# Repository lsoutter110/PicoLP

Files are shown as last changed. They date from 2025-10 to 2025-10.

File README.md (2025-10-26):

# PicoLP

STM32 development board, designed within the Raspberry Pi Pico footprint.

## Getting Started

A pinout for the board is provided in `documentation`, and example projects are provided in `firmware`. To build an example using CMake/VSCode:
- Clone the repo
- Import the project with the STM32Cube extension
- Configure the build options when prompted (Debug/Release)
- Configure as default and run the Build+Flash task with the STLink attached to the board

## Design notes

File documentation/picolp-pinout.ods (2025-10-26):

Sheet: template
NRST |  |  |  |  | VIN
3V3 |  |  |  |  | 3V3
GND |  |  |  |  | GND
B3 |  |  |  |  | A15
B4 |  |  |  |  | A10
B5 |  |  |  |  | A9
B6 |  |  |  |  | A8
GND |  |  |  |  | GND
B7 |  |  |  |  | B15
B8 |  |  |  |  | B14
B9 |  |  |  |  | B13
A0 |  |  |  |  | B12
GND |  |  |  |  | GND
A1 |  |  |  |  | B11
A2 |  |  |  |  | B10
A3 |  |  |  |  | B2
A4 |  |  |  |  | B1
GND |  |  |  |  | GND
A5 |  |  |  |  | B0
A6 |  |  |  |  | A7
 | PVIN | SWDIO | SWCLK | GND

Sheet: L051
TIM | I2C | SPI | UART | ADC | PIN |  |  |  |  | PIN | ADC | UART | SPI | I2C | TIM
 |  |  |  |  | NRST |  |  |  |  | VIN
 |  |  |  |  | 3V3 |  |  |  |  | 3V3
 |  |  |  |  | GND |  |  |  |  | GND
2CH2 |  | 1SCK |  |  | B3 |  |  |  |  | A15 |  | 2RX | 1NSS |  | 2CH1
22CH1 |  | 1MISO |  |  | B4 |  |  |  |  | A10 |  | 1RX
22CH2 |  | 1MOSI |  |  | B5 |  |  |  |  | A9 |  | 1TX
 | 1SCL |  | 1TX |  | B6 |  |  |  |  | A8
 |  |  |  |  | GND |  |  |  |  | GND
L1IN2 | 1SDA |  | 1RX |  | B7 |  |  |  |  | B15 |  |  | 2MOSI
 | 1SCL |  |  |  | B8 |  |  |  |  | B14 |  |  | 2MISO | 2SDA | 21CH2
 | 1SDA | 2NSS |  |  | B9 |  |  |  |  | B13 |  |  | 2SCK | 2SCL | 21CH1
2CH1 |  |  |  | IN0 | A0 |  |  |  |  | B12 |  |  | 2NSS
 |  |  |  |  | GND |  |  |  |  | GND
2CH2 |  |  |  | IN1 | A1 |  |  |  |  | B11 |  | L1RX |  | 2SDA | 2CH4
2CH3 |  |  | 2TX | IN2 | A2 |  |  |  |  | B10 |  | L1TX | 2SCK | 2SCL | 2CH3
2CH4 |  |  | 2RX | IN3 | A3 |  |  |  |  | B2 |  |  |  |  | L1OUT
 |  | 1NSS |  | IN4 | A4 |  |  |  |  | B1 | IN9
 |  |  |  |  | GND |  |  |  |  | GND
2CH1 |  | 1SCK |  | IN5 | A5 |  |  |  |  | B0 | IN8
22CH1 |  | 1MISO |  | IN6 | A6 |  |  |  |  | A7 | IN7 |  | 1MOSI |  | 22CH2
 |  |  |  |  | C13 | PVIN | SWDIO | SWCLK | GND

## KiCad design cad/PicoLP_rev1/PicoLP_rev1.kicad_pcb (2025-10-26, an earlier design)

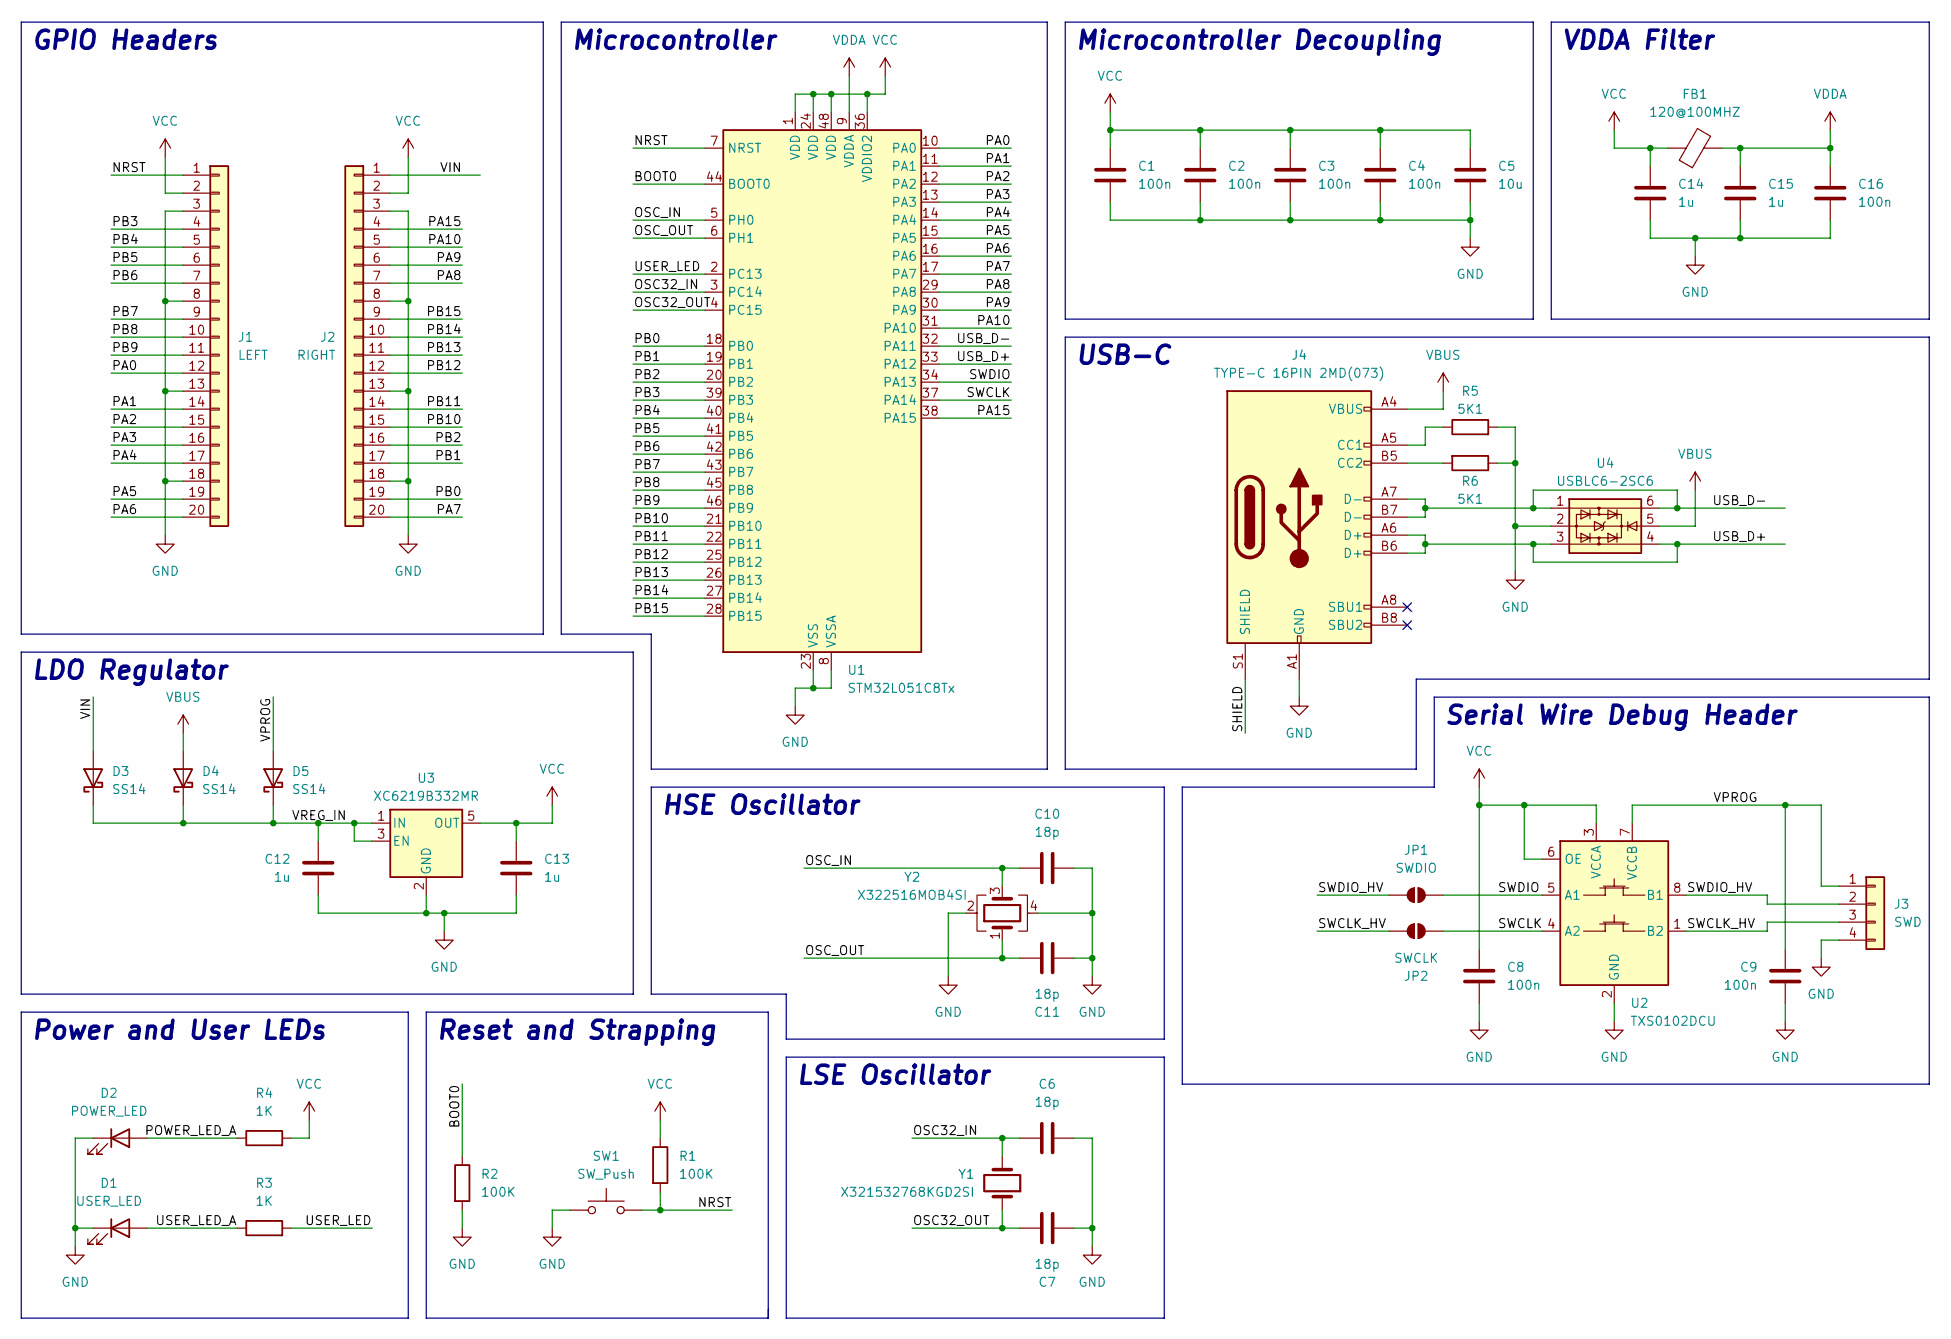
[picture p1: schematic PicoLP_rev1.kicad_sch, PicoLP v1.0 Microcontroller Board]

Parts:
C1, C2, C3, C4, C8, C9, C16: 100n; C_0402_1005Metric
C5: 10u; C_1206_3216Metric
C6, C7, C10, C11: 18p; C_0402_1005Metric
C12, C13, C14, C15: 1u; C_0603_1608Metric
D1: USER_LED; LED_0603_1608Metric
D2: POWER_LED; LED_0603_1608Metric
D3, D4, D5: SS14; D_SMA
FB1: 120@100MHZ; L_0603_1608Metric
J1: LEFT; PinHeader_1x20_P2.54mm_Vertical
J2: RIGHT; PinHeader_1x20_P2.54mm_Vertical
J3: SWD; PinHeader_1x04_P2.54mm_Vertical
J4: TYPE-C 16PIN 2MD(073); USB_C_Receptacle_GCT_USB4105-xx-A_16P_TopMnt_Horizontal
JP1: SWDIO; SolderJumper-2_P1.3mm_Open_TrianglePad1.0x1.5mm
JP2: SWCLK; SolderJumper-2_P1.3mm_Open_TrianglePad1.0x1.5mm
R1, R2: 100K; R_0603_1608Metric
R3, R4: 1K; R_0603_1608Metric
R5, R6: 5K1; R_0603_1608Metric
SW1: SW_Push; TS-1088
U1: STM32L051C8Tx; LQFP-48_7x7mm_P0.5mm
U2: TXS0102DCU; VSSOP-8_2.3x2mm_P0.5mm
U3: XC6219B332MR; SOT-23-5
U4: USBLC6-2SC6; SOT-23-6
Y1: X321532768KGD2SI; Crystal_SMD_3215-2Pin_3.2x1.5mm
Y2: X322516MOB4SI; Crystal_SMD_3225-4Pin_3.2x2.5mm

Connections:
/BOOT0: R2.1, U1.44 (BOOT0)
/NRST: J1.1, R1.2, SW1.2, U1.7 (NRST)
/OSC32_IN: C6.1, U1.3 (PC14), Y1.2
/OSC32_OUT: C7.1, U1.4 (PC15), Y1.1
/OSC_IN: C10.1, U1.5 (PH0), Y2.3
/OSC_OUT: C11.1, U1.6 (PH1), Y2.1
/PA0: J1.12, U1.10 (PA0)
/PA1: J1.14, U1.11 (PA1)
/PA2: J1.15, U1.12 (PA2)
/PA3: J1.16, U1.13 (PA3)
/PA4: J1.17, U1.14 (PA4)
/PA5: J1.19, U1.15 (PA5)
/PA6: J1.20, U1.16 (PA6)
/PA7: J2.20, U1.17 (PA7)
/PA8: J2.7, U1.29 (PA8)
/PA9: J2.6, U1.30 (PA9)
/PA10: J2.5, U1.31 (PA10)
/PA15: J2.4, U1.38 (PA15)
/PB0: J2.19, U1.18 (PB0)
/PB1: J2.17, U1.19 (PB1)
/PB2: J2.16, U1.20 (PB2)
/PB3: J1.4, U1.39 (PB3)
/PB4: J1.5, U1.40 (PB4)
/PB5: J1.6, U1.41 (PB5)
/PB6: J1.7, U1.42 (PB6)
/PB7: J1.9, U1.43 (PB7)
/PB8: J1.10, U1.45 (PB8)
/PB9: J1.11, U1.46 (PB9)
/PB10: J2.15, U1.21 (PB10)
/PB11: J2.14, U1.22 (PB11)
/PB12: J2.12, U1.25 (PB12)
/PB13: J2.11, U1.26 (PB13)
/PB14: J2.10, U1.27 (PB14)
/PB15: J2.9, U1.28 (PB15)
/POWER_LED_A: D2.2 (A), R4.1
/SHIELD: J4.S1 (SHIELD)
/SWCLK: JP2.2 (B), U1.37 (PA14), U2.4 (A2)
/SWCLK_HV: J3.3, JP2.1 (A), U2.1 (B2)
/SWDIO: JP1.2 (B), U1.34 (PA13), U2.5 (A1)
/SWDIO_HV: J3.2, JP1.1 (A), U2.8 (B1)
/USB_D+: J4.A6 (D+), J4.B6 (D+), U1.33 (PA12), U4.3, U4.4
/USB_D-: J4.A7 (D-), J4.B7 (D-), U1.32 (PA11), U4.1, U4.6
/USER_LED: R3.2, U1.2 (PC13)
/USER_LED_A: D1.2 (A), R3.1
/VIN: D3.2 (A), J2.1
/VPROG: C9.1, D5.2 (A), J3.1, U2.7 (VCCB)
/VREG_IN: C12.1, D3.1 (K), D4.1 (K), D5.1 (K), U3.1 (IN), U3.3 (EN)
GND: C1.2, C2.2, C3.2, C4.2, C5.2, C6.2, C7.2, C8.2, C9.2, C10.2, C11.2, C12.2, C13.2, C14.2, C15.2, C16.2, D1.1 (K), D2.1 (K), J1.3, J1.8, J1.13, J1.18, J2.3, J2.8, J2.13, J2.18, J3.4, J4.A1 (GND), J4.A12 (GND), J4.B1 (GND), J4.B12 (GND), R2.2, R5.2, R6.1, SW1.1, U1.8 (VSSA), U1.23 (VSS), U1.35 (VSS), U1.47 (VSS), U2.2 (GND), U3.2 (GND), U4.2, Y2.2, Y2.4
unnamed: J4.A5 (CC1), R5.1
unnamed: J4.B5 (CC2), R6.2
VBUS: D4.2 (A), J4.A4 (VBUS), J4.A9 (VBUS), J4.B4 (VBUS), J4.B9 (VBUS), U4.5
VCC: C1.1, C2.1, C3.1, C4.1, C5.1, C8.1, C13.1, C14.1, FB1.1, J1.2, J2.2, R1.1, R4.2, U1.1 (VDD), U1.24 (VDD), U1.36 (VDDIO2), U1.48 (VDD), U2.3 (VCCA), U2.6 (OE), U3.5 (OUT)
VDDA: C15.1, C16.1, FB1.2, U1.9 (VDDA)

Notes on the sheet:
Reset and Strapping
HSE Oscillator
Serial Wire Debug Header
GPIO Headers
LDO Regulator
LSE Oscillator
USB-C
Power and User LEDs
Microcontroller
VDDA Filter
Microcontroller Decoupling

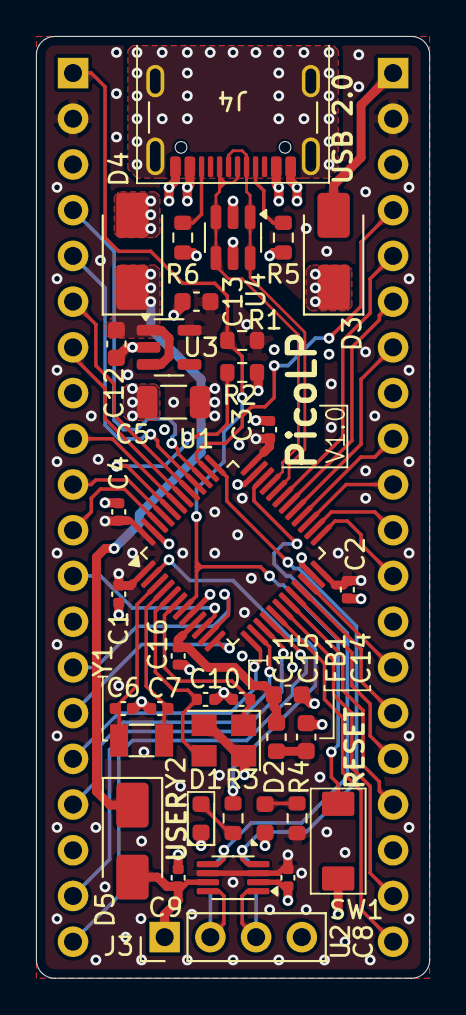
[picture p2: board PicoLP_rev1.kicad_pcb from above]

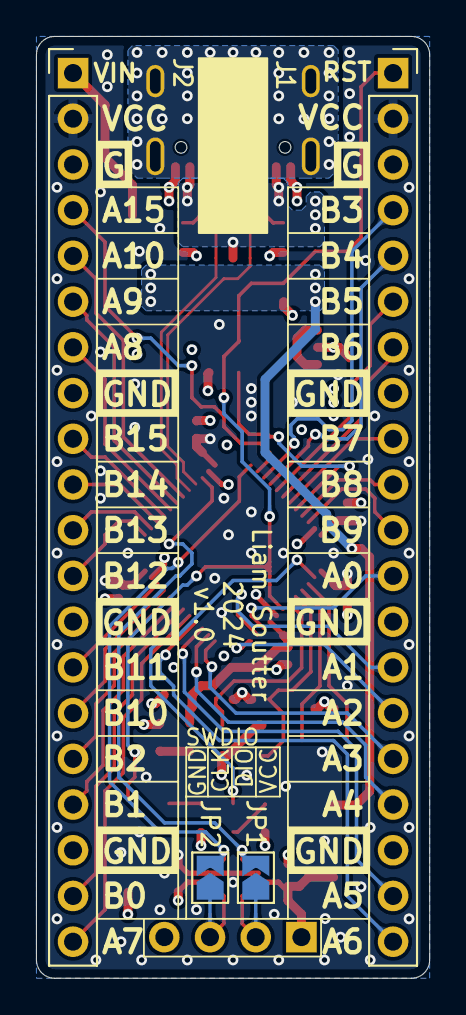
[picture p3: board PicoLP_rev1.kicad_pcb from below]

Board: 4 copper layers, 21.8 x 52.3 mm, 41 parts (4 on the bottom side), 52 nets.

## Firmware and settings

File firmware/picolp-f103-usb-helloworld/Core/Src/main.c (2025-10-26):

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
/* Includes ------------------------------------------------------------------*/
#include "main.h"
#include "usb_device.h"

/* USER CODE BEGIN Includes */

#include "usbd_cdc_if.h"

/* USER CODE END Includes */

TIM_HandleTypeDef htim1;

void SystemClock_Config(void);
static void MX_GPIO_Init(void);
static void MX_TIM1_Init(void);
/**
  * @brief  The application entry point.
  * @retval int
  */
int main(void)
{

  /* MCU Configuration--------------------------------------------------------*/

  /* Reset of all peripherals, Initializes the Flash interface and the Systick. */
  HAL_Init();

  /* Configure the system clock */
  SystemClock_Config();

  /* Initialize all configured peripherals */
  MX_GPIO_Init();
  MX_TIM1_Init();
  MX_USB_DEVICE_Init();
  /* USER CODE BEGIN 2 */

  HAL_TIM_Base_Start_IT(&htim1);
  HAL_TIM_OC_Start_IT(&htim1, TIM_CHANNEL_1);

  /* USER CODE END 2 */

  /* Infinite loop */
  /* USER CODE BEGIN WHILE */
  while (1)
  {
    /* USER CODE END WHILE */

    /* USER CODE BEGIN 3 */
  }
  /* USER CODE END 3 */
}

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
/* USER CODE BEGIN 4 */

void HAL_TIM_PeriodElapsedCallback(TIM_HandleTypeDef *htim) {
	const char tx_data[] = "Hello world!\r\n";
	if(CDC_Transmit_FS(tx_data, sizeof(tx_data)) == USBD_OK) {
		HAL_GPIO_WritePin(USER_LED_GPIO_Port, USER_LED_Pin, GPIO_PIN_SET);
	}
}

void HAL_TIM_OC_DelayElapsedCallback(TIM_HandleTypeDef *htim) {
	HAL_GPIO_WritePin(USER_LED_GPIO_Port, USER_LED_Pin, GPIO_PIN_RESET);
}

/* USER CODE END 4 */
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


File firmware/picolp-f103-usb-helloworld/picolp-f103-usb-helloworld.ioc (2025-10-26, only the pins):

Mcu.UserName=STM32F103CBTx
PA11.Signal=USB_DM
PA12.Signal=USB_DP
PA13.Signal=SYS_JTMS-SWDIO
PA14.Signal=SYS_JTCK-SWCLK
PC13-TAMPER-RTC.GPIO_Label=USER_LED
PC13-TAMPER-RTC.Signal=GPIO_Output
PD0-OSC_IN.Signal=RCC_OSC_IN
PD1-OSC_OUT.Signal=RCC_OSC_OUT

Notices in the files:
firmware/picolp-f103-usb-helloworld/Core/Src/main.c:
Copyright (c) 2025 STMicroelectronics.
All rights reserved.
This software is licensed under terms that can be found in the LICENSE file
